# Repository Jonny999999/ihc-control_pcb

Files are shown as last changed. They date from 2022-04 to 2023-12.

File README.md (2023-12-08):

Repo for designing a custom pcb that controlls the electrical components of an IHC-Tractor.

# TOC
- [Links](#links)
- [Overview](#overview)
- [Open Schematic and Layout](#open-schematic-and-layout)
- [Connector Pin-assignment](#connector-pin-assignment)
  * [New Connectors](#new-connectors)
  * [Old Connectors](#old-connectors)
- [I/O List](#i-o-list)
  * [Switches](#switches)
  * [Relays](#relays)
- [Instructions (milling process)](#instructions--milling-process-)
  * [Step 1: export files](#step-1--export-files)
  * [Step 2: generate gcode (holes, traces, outline)](#step-2--generate-gcode--holes--traces--outline-)
  * [Step 3: generate gcode (engraving text)](#step-3--generate-gcode--engraving-text-)
  * [Step 4: mill outline](#step-4--mill-outline)
  * [Step 5: post processing](#step-5--post-processing)
- [Notes for next version (pcb design)](#notes-for-next-version--pcb-design-)
- [Notes for next pcb (milling)](#notes-for-next-pcb-milling)
  * [CNC-Control (WinPC-NC)](#cnc-control--winpc-nc-)
    + [Parameters](#parameters)
    + [Occurred problems](#occurred-problems)
  * [G-code generation (pcb2gcode)](#g-code-generation--pcb2gcode-)
    + [Notes for next time](#notes-for-next-time-)
    + [Gerber export (kicad)](#gerber-export--kicad-)

# Links
- Project documentation: https://pfusch.zone/control-pcb
- Firmware repo: https://github.com/Jonny999999/ihc-control_fw

# Overview
### Schematic
[pcb-ihc_schem_v4-milled-v1.1.pdf](/kicad/export/pcb-ihc_schem_v4-milled-v1.1.pdf)

### PCB-layout
<p align="center">
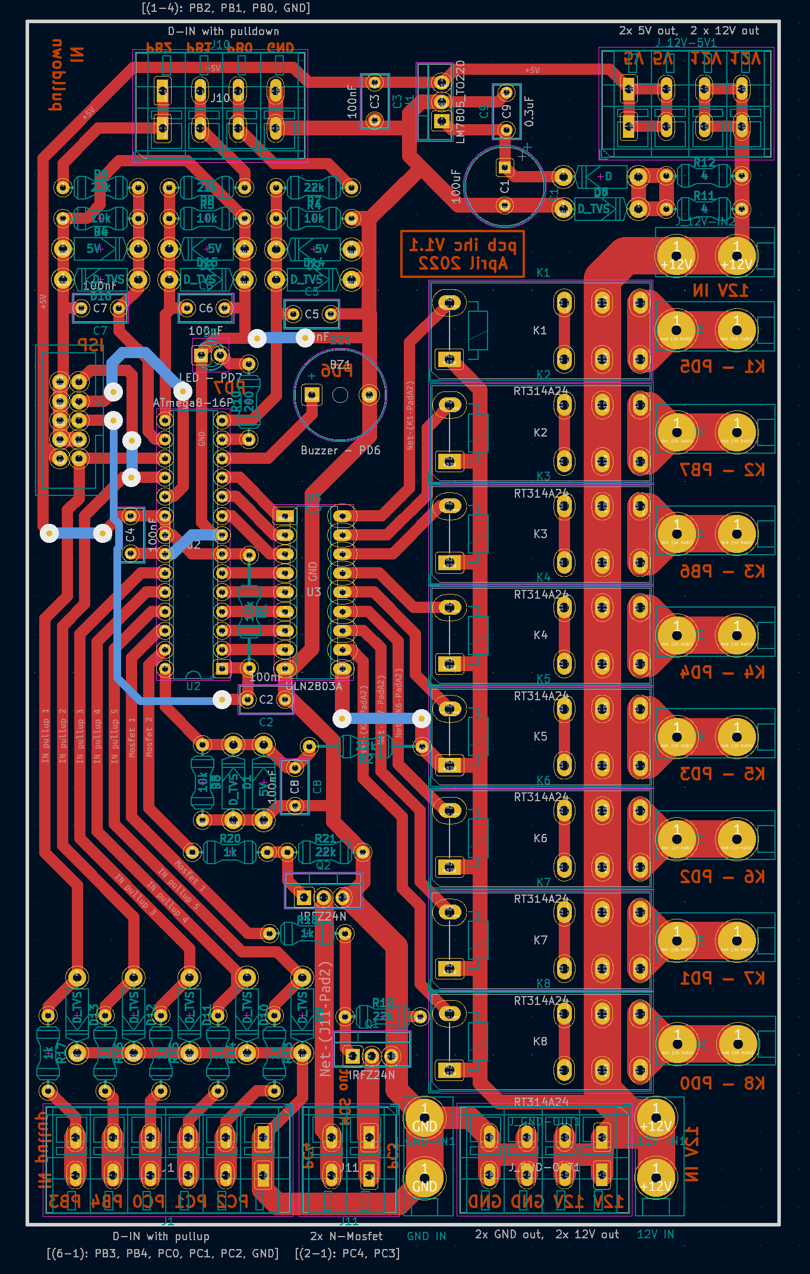
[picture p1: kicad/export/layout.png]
  
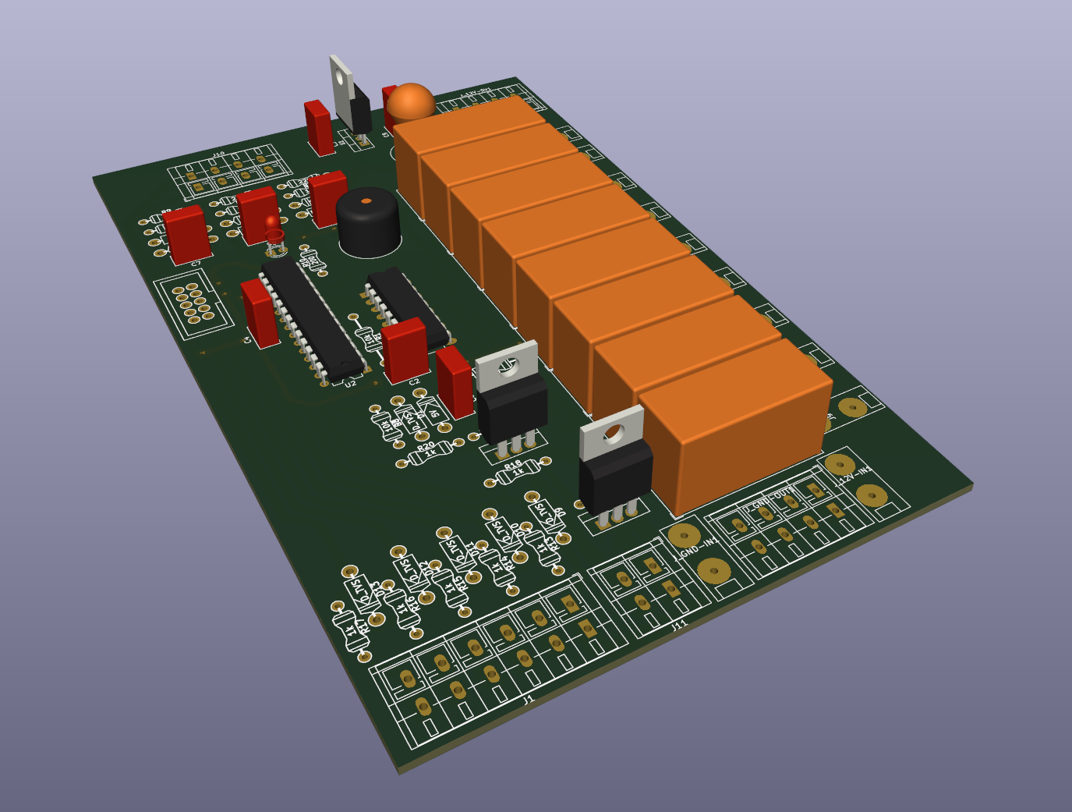
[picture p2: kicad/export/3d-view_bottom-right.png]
  
</p>

# Open Schematic and Layout
Install kicad and open /kicad/pcb-ihc_kicad.kicad_pro  

For quickly viewing the current schematic and layout without installing kicad see exported files in
`kicad/export` or complete documentation at https://pfusch.zone

# Connector Pin-assignment
## New Connectors
See plan in firmware repo: 
https://github.com/Jonny999999/ihc-control_fw/blob/master/connection-plan.pdf

## Old Connectors
### 2 Pole connector 6mm2:
- 1: Starter motor (9)
- 2: Glowplug

### 6 Pole PC (3)
- 1: empty
- 2: Front light right, left (top right)
- 2a: Switch brakelight LS 1/2
- 3: Horn 1/2
- 3a Switch brakelight LS 2/2
- 4: Light left AL, right AR (bottom right)

### 6 Pole PB (2)
- 1: (20) Starter motor (relay) (top left)
- 2: (22) Fuel sensord
- 3: (24) Horn 2/2
- 4: (26) Oil pressure (switch to gnd)
- 5: (28) Temperature sensor
- 6: (30) Voltage regulator alternator (?)

### 6 Pole PA (1)
- 1: (31,32) FD sidelight -> trailer connector
- 2: (37) LB LB Light left -> trailer connector
- 3: (90) Side light BR
- 4: (88) Side light BL
- 5: (43, 42) FA -> trailer connector
- 6: (48) LA light left -> trailer connector

# I/O List
List of required I/O pins for planning the board
## Switches
### Switch to GND (pullup input)
- S_Warning Lights
- S_TurnLeft  toggle
- S_TurnRight toggle
- S_HighBeam  momentary
- S_Warning Lights  toggle
- S_Horn

### Switch to 12V (pulldown input)
- S_ParkingLight
- S_LowBeam
- S_Brake

### Notes
- S_worklight !!! no input left?!

## Relays
- K_BlinkLeft
- K_BlinkRight
- K_ParkingLight
- K_LowBeam
- K_HighBeam
- K_Horn

# Instructions (milling process)
Machine used: Stepcraft 420
## Step 1: export files
- Kicad: Export/plot pcb to gerber files
  Note: Also export User1 layer (includes text for engraving)
- Kicad: Generate drill file
```
back=./in/pcb-ihc_kicad-B_Cu.gbr
front=./in/pcb-ihc_kicad-F_Cu.gbr
outline=./in/pcb-ihc_kicad-Edge_Cuts.gbr
drill=./in/pcb-ihc_kicad-PTH.drl
see config file: pcb2gcode/millproject
```

## Step 2: generate gcode (holes, traces, outline)
- run pcb2gcode: `ihc-control_pcb/pcb2gcode> pcb2gcode`  
  will use millproject file for parameters as default config

## Step 3: generate gcode (engraving text)
- Kicad: moved text to be engraved into pcb on separate layer (User1)
- Also export/plot User1 layer with other gerber files
- Use separate millproject_text parameter file with pcb2gcode
  `pcb2gcode --config millproject_text`
NOTE: also include outline and maybe front in that millproject, even though that output is not used. It is necessary that the origin fits, otherwise there will be an offset!
- The trick was to use a negative offest (almost half the line width) to get more or less clean characters
- Generates pcb2gcode/out/text/back.ngc
Note: check if there is an offset/scaling issue to other files (back, drill). last time text got engraved into traces even though it matched on the other side

## Step 4: mill outline
Was not necessary in this case because size already matched

## Step 5: post processing
- Slightly smooth copper layer of pcb using grinding wool
- Drill holes for big 4mm2 2-pin terminals to 1.5mm if drilled with just 1mm on cnc

# Notes for next version (pcb design)
- Add resistor and diode for slowly charging the input capacitor (limit charging current)
- Add diode and/or jumper for isp programmer. Noticed that current is flowing from board 5v to programmer (input resistor got hot - only when programme connected) (alternatively jumper on programmer can be used for this...)
- ADD FUSES
  - Add fuse for 12v supply to 5v regulator
  - Fuses for mosfets?
  - Fuses for relay?
- Add mounting holes / at least make some space for third hole
- Slightly smaller size for easier cnc-milling

# Notes for next pcb milling
## CNC-Control (WinPC-NC)
### Parameters
- WinPC-NC has weird default z coorinates direction
  => **Z coordinates have to be inverted (!!!!!)** (otherwise will crash)
  -> parameters -> dateiformat -> z-koordinaten invertieren
- Change units to mm/min instead of default mm/s
### Occurred problems
- Problem Stepper not moving, only producing noise, but winpc-nc actually thinks that it moved coordinates - especially happened for Z-Axis
  - Solution 1: remove top section of gcode (simple G1 commands worked - see gcode generated with estlcam that is compatible)
  - Solution 2: switch from windows in Virtualbox to native windows

## G-code generation (pcb2gcode)
### notes for next time:
TODO: merge this section with milling instructions?
- Text engraving: slightly reduce Z depth 
- Zero Z-axis on multiple places: 
  At 2 edges pcb material was apparently lower, thus only scratched the surface -> had to mill again
- Zero-XY NOT at file origin! (the offset is caused by outline cutter diameter) 
  - 1. Load outline gcode, zero x,y next to border (note offset) 
  - 2. Confirm with moving on other side of pcb
- Make screenshot of absolute coordinates of origin (in case of accidential shift / position loss)
- Check position before drilling holes
- Fixing the pcb: Screws around the pcb are probably enough (check bend)
- When generating gcode for text separately, also include at least outline, otherwise there is an offset (origin makes no sense)

### Gerber export (kicad)
- design pcb slightly smaller for more tolerance...
- define custom origin 
  => tried this, setting "drill/place file origin" and tick the checkbox at plot, but had no effect to pcb2gcode in any way
- check if origin is the same in every gerber/gcode file (verify with gcode viewer?)

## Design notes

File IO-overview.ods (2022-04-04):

 | IN Switches |  |  |  |  | OUT Relay
N. | Location | Variable name | Switch type | Connection type | N. | Variable name
1 | dashboard | S_Warning Lights | toggle | NO, low | 1 | K_BlinkLeft
2 | dashboard | S_TurnLeft | toggle | NO, low | 2 | K_BlinkRight
3 | dashboard | S_TurnRight | toggle | NO, low | 3 | K_ParkingLight
4 | dashboard | S_HighBeam | momentary | NO, low | 4 | K_LowBeam
5 | dashboard | S_Horn | momentary | NO, low | 5 | K_HighBeam
 |  |  |  |  | 6 | K_Horn?
6 | Key | S_ParkingLight | toggle | NO, high | 7 | K_hinten
7 | Key | S_LowBeam | toggle | NO, high | 8
 |  |  |  |  |  | bremslicht blinkern nur hinten
8 | Brake | S_Brake | momentary | NO, high
 |  |  |  |  |  | OUT Direct
 | IN Analog |  |  |  | 1 | LED switch???
 | Location | Variable name |  |  | 2 | LED PCB
1 | pcb | IN_Voltage |  |  | 3 | Buzzer
 | Notes / Ideas: |  |  |  |  | OUT Mosfet
 | LED for each relay?
 | switch horn?

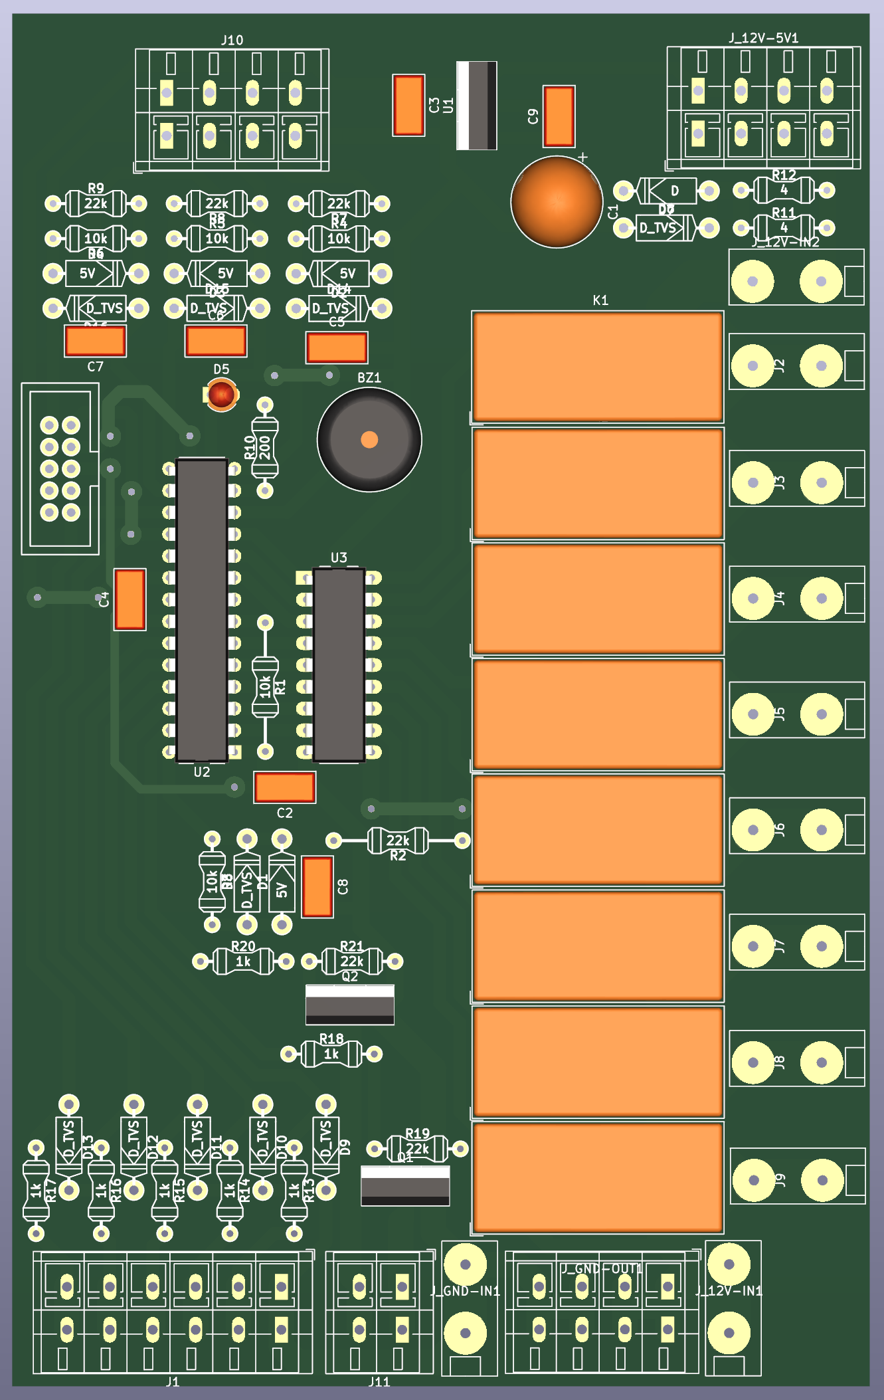
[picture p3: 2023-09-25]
kicad/export/3d-view_top.png

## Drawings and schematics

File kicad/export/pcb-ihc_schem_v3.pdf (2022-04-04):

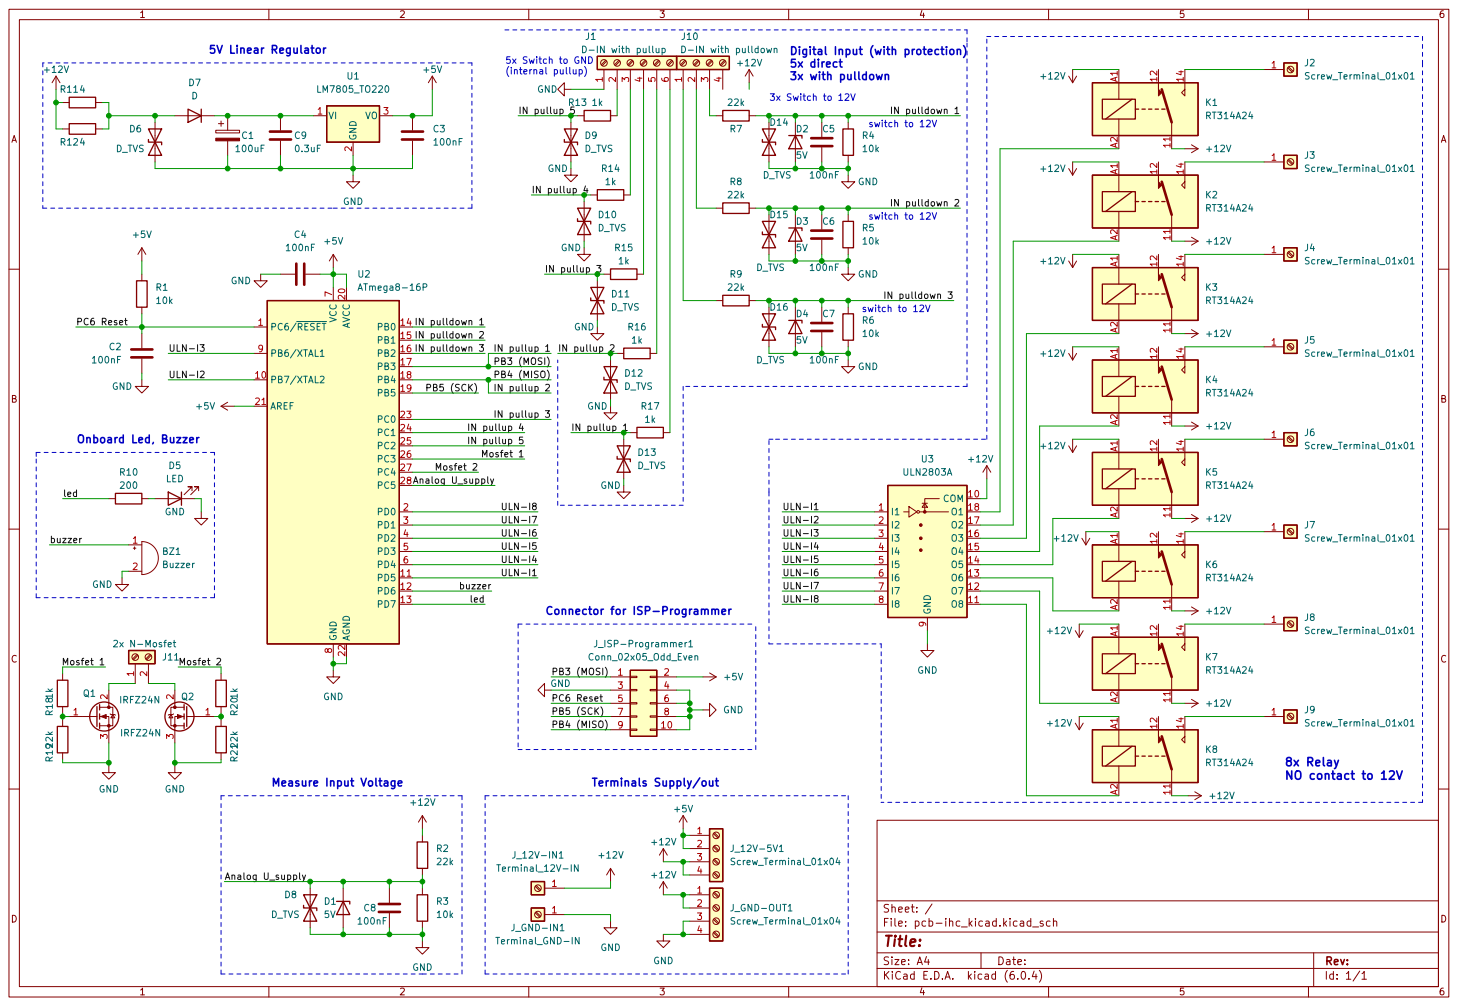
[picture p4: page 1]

switch to 12V Measure Input Voltage

IN pullup 3
IN pullup 3 ULN-I7 PB4 (MISO) ULN-I5 ULN-I6

switch to 12V Onboard Led, Buzzer

Connector for ISP-Programmer

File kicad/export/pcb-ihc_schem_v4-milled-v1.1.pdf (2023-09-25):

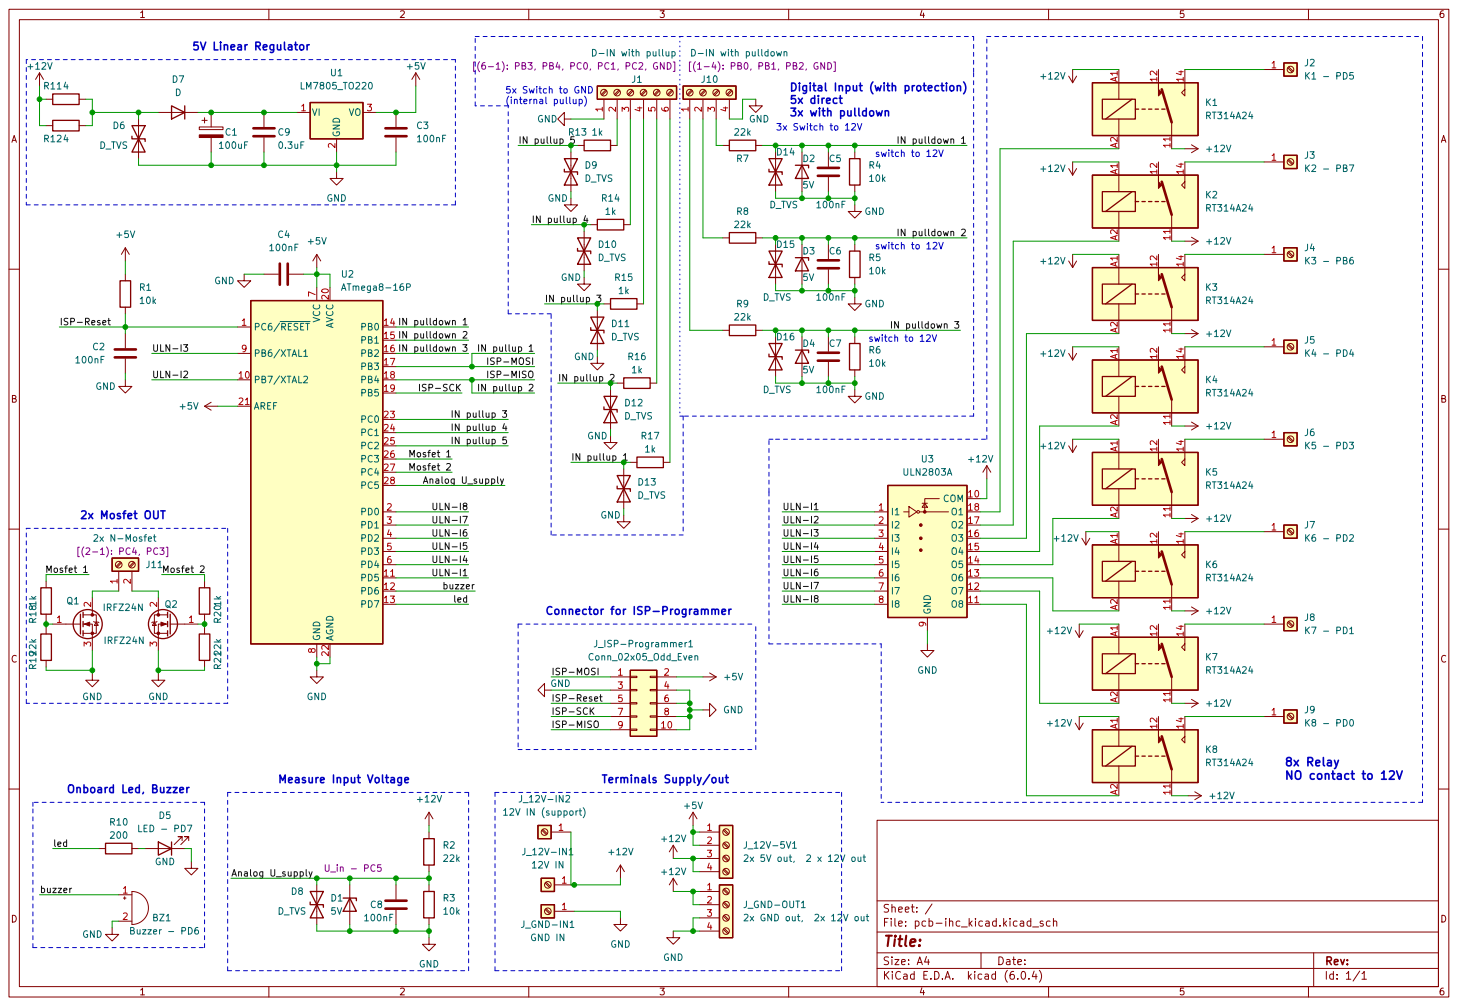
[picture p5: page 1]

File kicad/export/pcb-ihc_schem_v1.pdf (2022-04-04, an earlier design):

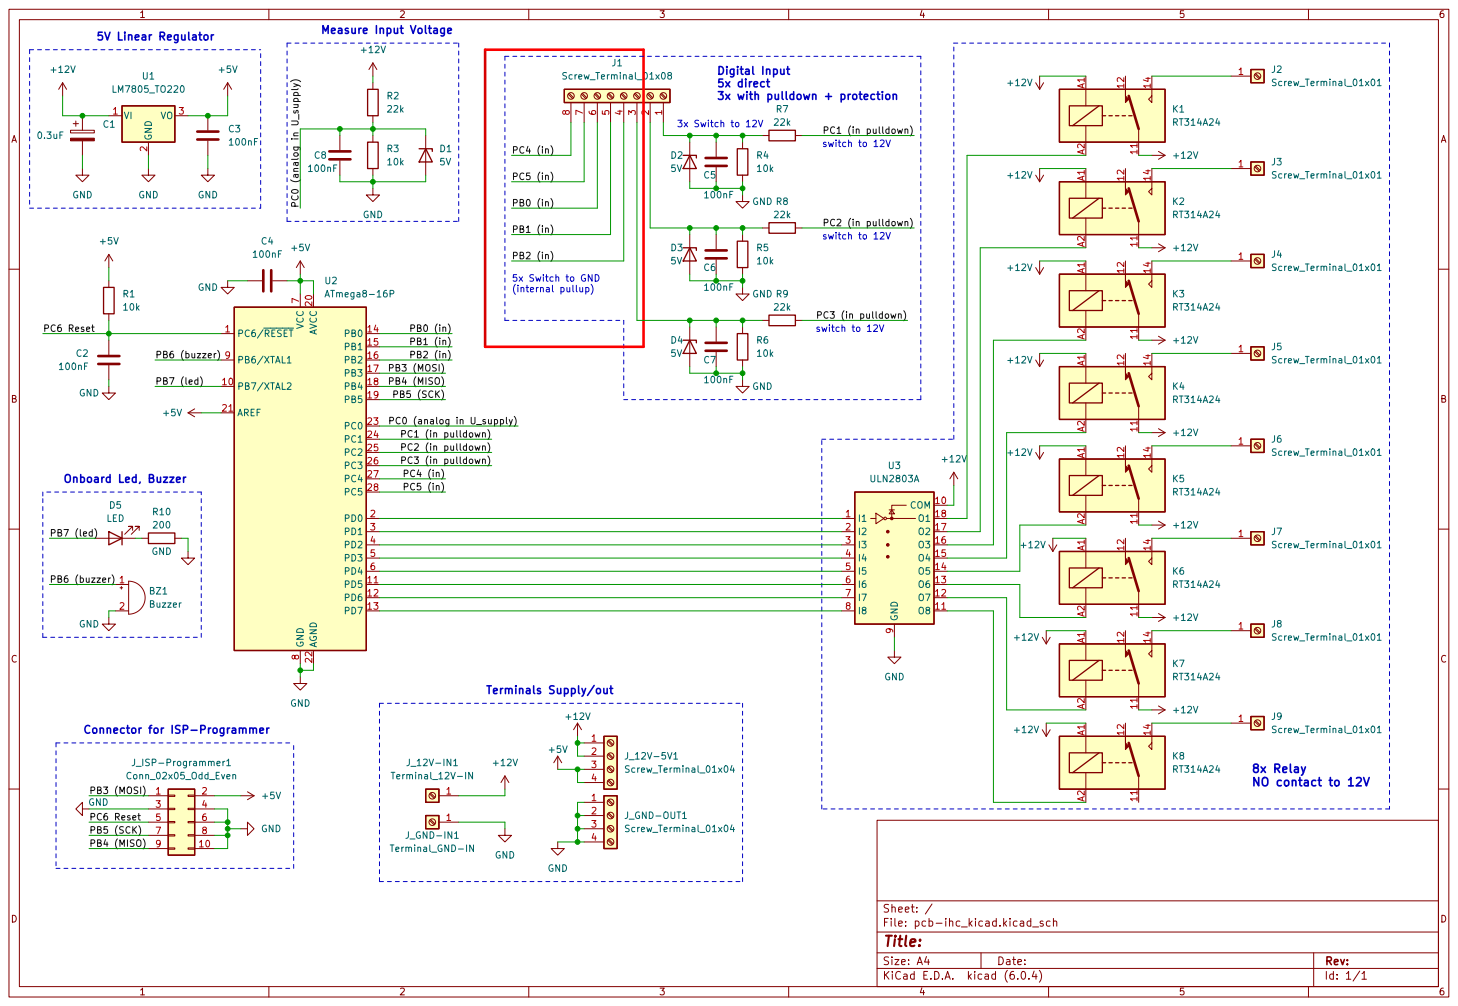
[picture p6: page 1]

Digital Input 5x direct 3x with pulldown + protection

I3 3
I4 4
I5 5
I6 6
I7 7

File: pcb-ihc_kicad.kicad_sch Sheet: / GND

Connector for ISP-Programmer

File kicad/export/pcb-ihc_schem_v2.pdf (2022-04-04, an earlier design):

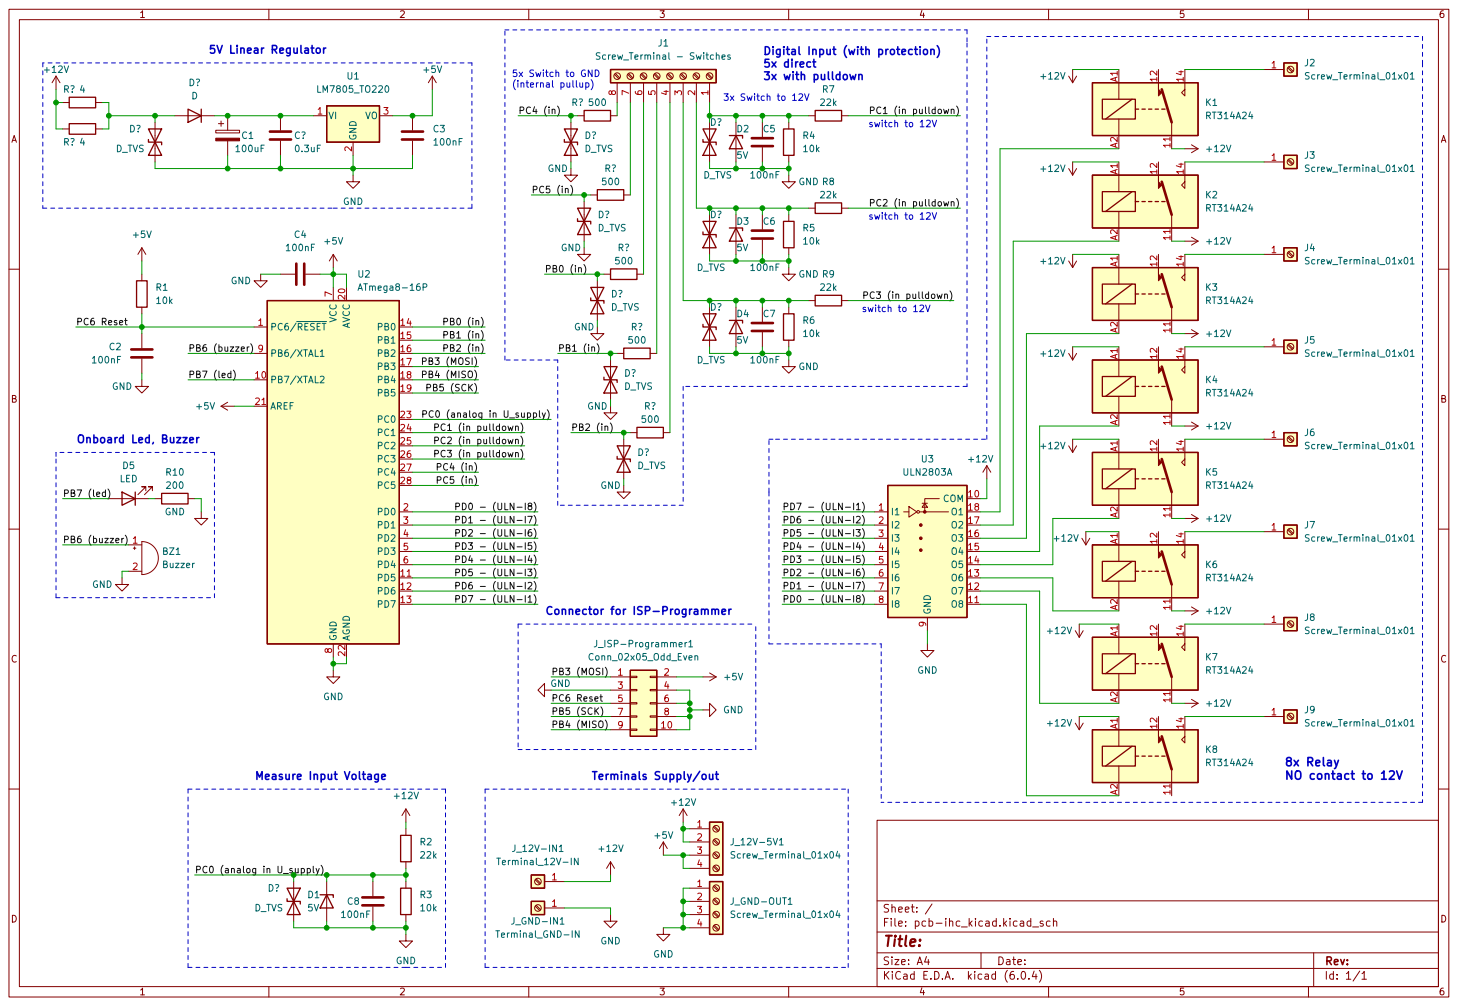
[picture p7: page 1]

Digital Input (with protection) 5x direct 3x with pulldown

Connector for ISP-Programmer

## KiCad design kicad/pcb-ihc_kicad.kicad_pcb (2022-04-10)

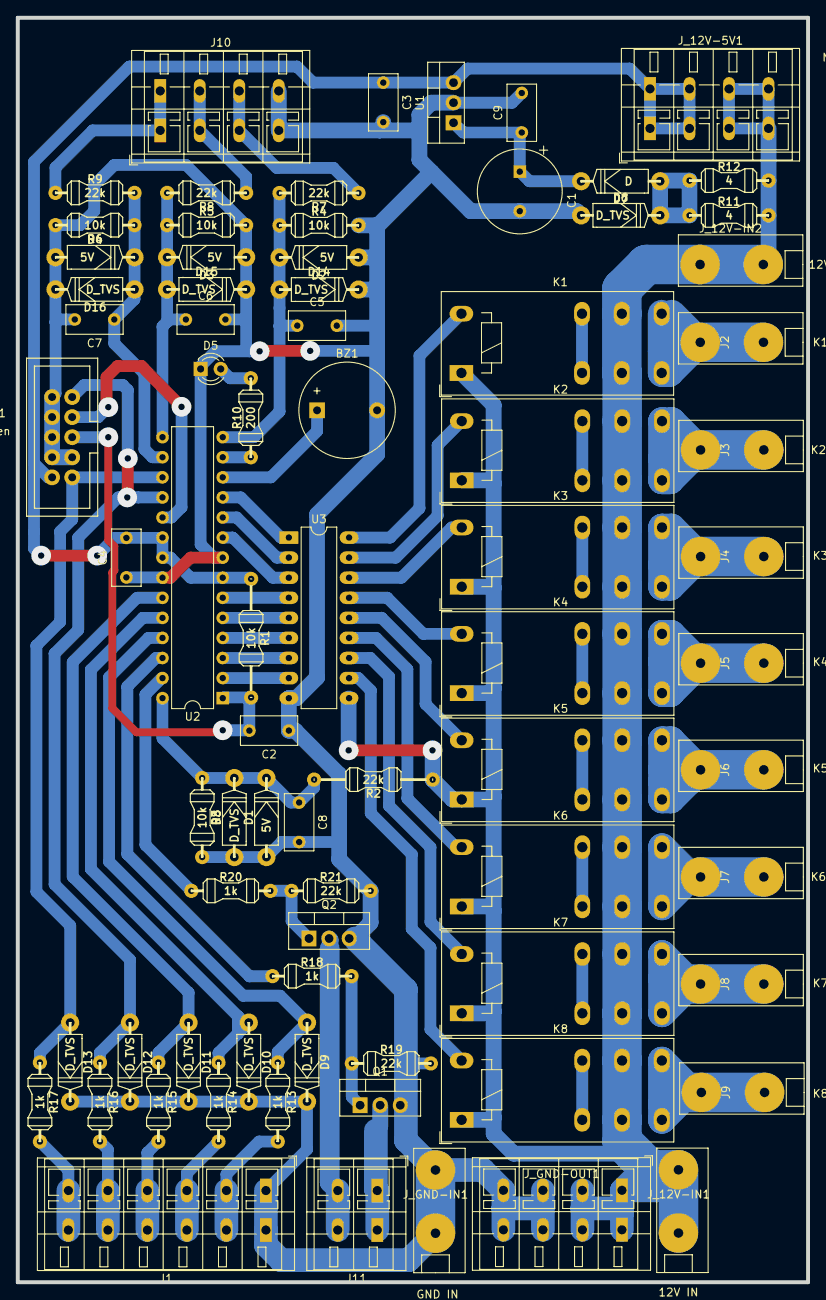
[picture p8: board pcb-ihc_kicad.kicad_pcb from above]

Board: 2 copper layers, 100.0 x 160.0 mm, 77 parts (0 on the bottom side), 57 nets.

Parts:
BZ1: Buzzer - PD6; Buzzer_12x9.5RM7.6
C1: 100uF; CP_Radial_Tantal_D10.5mm_P5.00mm
C2, C3, C4, C5, C6, C7, C8: 100nF; C_Rect_L7.0mm_W3.5mm_P5.00mm
C9: 0.3uF; C_Rect_L7.0mm_W3.5mm_P5.00mm
D1, D2, D3, D4: 5V; my_D10_11
D5: LED - PD7; LED_D3.0mm
D6, D8, D9, D10, D11, D12, D13, D14, D15, D16: D_TVS; my_D10_11
D7: D; my_D10_11
J1: D-IN with pullup; TerminalBlock_WAGO_236-406_1x06_P5.00mm_45Degree
J2: K1 - PD5; my_KlemmeWago2604-single
J3: K2 - PB7; my_KlemmeWago2604-single
J4: K3 - PB6; my_KlemmeWago2604-single
J5: K4 - PD4; my_KlemmeWago2604-single
J6: K5 - PD3; my_KlemmeWago2604-single
J7: K6 - PD2; my_KlemmeWago2604-single
J8: K7 - PD1; my_KlemmeWago2604-single
J9: K8 - PD0; my_KlemmeWago2604-single
J10: D-IN with pulldown; TerminalBlock_WAGO_236-404_1x04_P5.00mm_45Degree
J11: 2x N-Mosfet; TerminalBlock_WAGO_236-402_1x02_P5.00mm_45Degree
J_12V-5V1: 2x 5V out, 2 x 12V out; TerminalBlock_WAGO_236-404_1x04_P5.00mm_45Degree
J_12V-IN1: 12V IN; my_KlemmeWago2604-single
J_12V-IN2: 12V IN (support); my_KlemmeWago2604-single
J_GND-IN1: GND IN; my_KlemmeWago2604-single
J_GND-OUT1: 2x GND out, 2x 12V out; TerminalBlock_WAGO_236-404_1x04_P5.00mm_45Degree
J_ISP-Programmer1: Conn_02x05_Odd_Even; my_wannenstecker_2x5
K1, K2, K3, K4, K5, K6, K7, K8: RT314A24; Relay_SPDT_Schrack-RT1-16A-FormC_RM5mm
Q1, Q2: IRFZ24N; TO-220-3_Vertical
R1: 10k; my_R15-long
R2: 22k; my_R15-long
R3, R4, R5, R6: 10k; my_R10
R7, R8, R9, R19, R21: 22k; my_R10
R10: 200; my_R10
R11, R12: 4; my_R10
R13, R14, R15, R16, R17, R18, R20: 1k; my_R10
U1: LM7805_TO220; TO-220-3_Vertical
U2: ATmega8-16P; DIP-28_W7.62mm
U3: ULN2803A; DIP-18_W7.62mm_LongPads

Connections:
+5V: C3.1, C4.2, J_12V-5V1.1, J_12V-5V1.2, J_ISP-Programmer1.2, R1.1, U1.3 (VO), U2.7 (VCC), U2.20 (AVCC), U2.21 (AREF)
+12V: J_12V-5V1.3, J_12V-5V1.4, J_12V-IN1.1, J_12V-IN2.1, J_GND-OUT1.1, J_GND-OUT1.2, K1.11, K1.A1, K2.11, K2.A1, K3.11, K3.A1, K4.11, K4.A1, K5.11, K5.A1, K6.11, K6.A1, K7.11, K7.A1, K8.11, K8.A1, R2.1, R11.2, R12.2, U3.10 (COM)
/Analog U_supply: C8.1, D1.1 (K), D8.1 (A1), R2.2, R3.1, U2.28 (PC5)
/IN pulldown 1: C5.1, D2.1 (K), D14.2 (A2), R4.1, R7.2, U2.14 (PB0)
/IN pulldown 2: C6.1, D3.1 (K), D15.2 (A2), R5.1, R8.2, U2.15 (PB1)
/IN pulldown 3: C7.1, D4.1 (K), D16.2 (A2), R6.1, R9.2, U2.16 (PB2)
/IN pullup 1: D13.2 (A2), J_ISP-Programmer1.1, R17.1, U2.17 (PB3)
/IN pullup 2: D12.2 (A2), J_ISP-Programmer1.9, R16.1, U2.18 (PB4)
/IN pullup 3: D11.2 (A2), R15.1, U2.23 (PC0)
/IN pullup 4: D10.2 (A2), R14.1, U2.24 (PC1)
/IN pullup 5: D9.2 (A2), R13.1, U2.25 (PC2)
/ISP-Reset: C2.2, J_ISP-Programmer1.5, R1.2, U2.1 (PC6/~RESET)
/ISP-SCK: J_ISP-Programmer1.7, U2.19 (PB5)
/Mosfet 1: R18.1, U2.26 (PC3)
/Mosfet 2: R20.1, U2.27 (PC4)
/ULN-I1: U2.11 (PD5), U3.1 (I1)
/ULN-I2: U2.10 (PB7/XTAL2), U3.2 (I2)
/ULN-I3: U2.9 (PB6/XTAL1), U3.3 (I3)
/ULN-I4: U2.6 (PD4), U3.4 (I4)
/ULN-I5: U2.5 (PD3), U3.5 (I5)
/ULN-I6: U2.4 (PD2), U3.6 (I6)
/ULN-I7: U2.3 (PD1), U3.7 (I7)
/ULN-I8: U2.2 (PD0), U3.8 (I8)
/buzzer: BZ1.1 (-), U2.12 (PD6)
/led: R10.1, U2.13 (PD7)
GND: BZ1.2 (+), C1.2, C2.1, C3.2, C4.1, C5.2, C6.2, C7.2, C8.2, C9.2, D1.2 (A), D2.2 (A), D3.2 (A), D4.2 (A), D5.1 (K), D6.2 (A2), D8.2 (A2), D9.1 (A1), D10.1 (A1), D11.1 (A1), D12.1 (A1), D13.1 (A1), D14.1 (A1), D15.1 (A1), D16.1 (A1), J1.1, J10.4, J_GND-IN1.1, J_GND-OUT1.3, J_GND-OUT1.4, J_ISP-Programmer1.3, J_ISP-Programmer1.4, J_ISP-Programmer1.6, J_ISP-Programmer1.8, J_ISP-Programmer1.10, Q1.3 (S), Q2.3 (S), R3.2, R4.2, R5.2, R6.2, R19.2, R21.2, U1.2 (GND), U2.8 (GND), U2.22 (AGND), U3.9 (GND)
unnamed: C1.1, C9.1, D7.1 (K), U1.1 (VI)
unnamed: D5.2 (A), R10.2
unnamed: D6.1 (A1), D7.2 (A), R11.1, R12.1
unnamed: J1.2, R13.2
unnamed: J1.3, R14.2
unnamed: J1.4, R15.2
unnamed: J1.5, R16.2
unnamed: J1.6, R17.2
unnamed: J2.1, K1.14
unnamed: J3.1, K2.14
unnamed: J4.1, K3.14
unnamed: J5.1, K4.14
unnamed: J6.1, K5.14
unnamed: J7.1, K6.14
unnamed: J8.1, K7.14
unnamed: J9.1, K8.14
unnamed: J10.1, R9.1
unnamed: J10.2, R8.1
unnamed: J10.3, R7.1
unnamed: J11.1, Q1.2 (D)
unnamed: J11.2, Q2.2 (D)
unnamed: K1.A2, U3.18 (O1)
unnamed: K2.A2, U3.17 (O2)
unnamed: K3.A2, U3.16 (O3)
unnamed: K4.A2, U3.15 (O4)
unnamed: K5.A2, U3.14 (O5)
unnamed: K6.A2, U3.13 (O6)
unnamed: K7.A2, U3.12 (O7)
unnamed: K8.A2, U3.11 (O8)
unnamed: Q1.1 (G), R18.2, R19.1
unnamed: Q2.1 (G), R20.2, R21.1

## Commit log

2022-04-04 init
    pcb layout is in progress, schematic needs optimizations
    [IO-overview.ods, pcb-ihc_kicad.dsn, pcb-ihc_kicad.kicad_pcb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]
2022-04-04 Add 2x Mosfet, Change labels, Change layout
    [pcb-ihc_kicad.kicad_pcb, pcb-ihc_kicad.kicad_sch, pcb-ihc_kicad_7.dsn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]
2022-04-04 Optimize layout
    [pcb-ihc_kicad.kicad_pcb, pcb-ihc_kicad_8.dsn, pcb-ihc_kicad_9.dsn]
2022-04-04 Routing first version ready for validation
    in this commit the entire routing of tracks was done. next step
    validation and optimizations.
    [pcb-ihc_kicad.kicad_pcb, pcb-ihc_kicad.kicad_sch, pcb-ihc_kicad_routing_1.dsn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]
2022-04-05 Optimize routing and layout
    - fix track width on several locations (1.5 to 2mm)
    - minor changes in routing
    - move relays closer together
    - add additional 12V input terminal
    [pcb-ihc_kicad.kicad_pcb, pcb-ihc_kicad.kicad_sch]
2022-04-05 Add gitignore, remove backups
    Add gitignore to ignore auto-save and backup files from kicad
2022-04-05 Add terminal descriptions, Clean up schematic
    - Add detailed terminal/connector descriptions (e.g. which uC pin)
    - Positioned labels in layout outside of pcb
    - cleanup in schematic reorder groups, fix boxes...
    [pcb-ihc_kicad.kicad_pcb, pcb-ihc_kicad.kicad_sch]
2022-04-06 Swap Layers Front/Back Tracks
    Noticed in 3d viewer that tracks were on the same side as components...
    swaped F.Cu and B.Cu using " Edit -> Swap layers ". Now tracks are on
    the other side...
    [pcb-ihc_kicad.kicad_pcb]
2022-04-07 Add text to copper back layer
    Add description of terminals (desc, controller pin) as text to copper
    layer. The plan is that the text is actually milled onto the pcb
    (like tracks)
    [pcb-ihc_kicad.kicad_pcb]
2022-04-07 Add pcb2gcode
    Created folder for pcb2gcode (to convert gerber files from kicad to
    gcode for winpc)
    Add config file
    tried to extract parameters from old gcode files of electric kart
    project (also converted with pcb2gcode)
    worked with pcb2gcode gui for some time but noticed it is quite
    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
    [pcb-ihc_kicad-B_Cu.gbr, pcb-ihc_kicad-Edge_Cuts.gbr, pcb-ihc_kicad-F_Cu.gbr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]
2022-04-07 Renamed kicad folder
    renamed folder pcb-ihc_kicad to kicad (project folder name describes
    project anyways)
    [pcb-ihc_kicad.kicad_pcb, pcb-ihc_kicad.kicad_sch]
2022-04-08 Add Readme, Add ihc-schematic
    Add readme for notes about the project
    Add downloaded ihc schematic for identification of pins
2022-04-08 Add gcode file for milling 162x102 plane for pcb
    copied old file generated using estlcam that mills an area 162x102mm
    0.7mm deep using a 6mm cutter
2022-04-09 Remove and ignore svg files of pcb2gcode from git
2022-04-09 Move text to User1 layer, adjust positions
    Move text that should be engraved to pcb from copper-back layer to user1
    layer (=> can be handled / processed separately with other parameters by
    pcb2gcode)
    also make line width to 0.3 for previous smaller text
    [pcb-ihc_kicad.kicad_pcb]
2022-04-09 pcb2gcode: Add millproject_text config
    Add separate parameter file for engraving text using separate exported User1
    layer
    [pcb-ihc_kicad-B_Cu.gbr, pcb-ihc_kicad-Edge_Cuts.gbr, pcb-ihc_kicad-F_Cu.gbr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]
2022-04-09 pcb2gcode: Change several parameters: zsafe, feed, drill...
    change zsafe from 5 to 2mm (z takes too long to move - faster)
    change zchange from 40 to 30 (unnecessary high exceeded working range
    when test-milling in air)
    change millfeed from 300 to 500 (appeared to slow - more room for adjustments to greater speeds while milling 0-200%)
    add drills avaialbe=0.8,1 (drilling with those diameters ony anyways -
    no unnecessary tool changes that get skipped anyways)
2022-04-09 readme: pcb2gcode details, IHC-schematic interpretation
    Tried to identify connector pins using ihc schematic
    Added description of engraving text using kicad and pcb2gcode
2022-04-09 Generated gcode of current pcb version
    [pcb-ihc_kicad-B_Cu.gbr, pcb-ihc_kicad-Edge_Cuts.gbr, pcb-ihc_kicad-F_Cu.gbr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]
2022-04-09 First milling: Update readme, gcode files
    First pcb got produced, there were several issues - see readme "notes
    for next time milling"
    gcode for text engraving is apparently scaled wrong? does not line up at
    the other side of pcb - this has to be looked into
    [pcb-ihc_kicad-User_2.gbr]
2022-04-10 Reduce length of pcb
    Layout: move top components closer together to have more "free space" on
    the top thus more tolerance when milling
    [pcb-ihc_kicad.kicad_pcb]
2022-04-10 pcb2gcode: Change outline side and cutter-diameter
    cutter diameter caused offset of origin in gcode files, which was quite
    confusing at first try. changed from 3mm to 0mm in both millproject and
    millproject_text
    changed cute-side to back, default was front which mirrored the gcode
    (wrong origin position)
2022-04-10 Minor optimization of text position
    [pcb-ihc_kicad.kicad_pcb]
2022-04-10 Generate gcode for second milling procedure
    Exported gerber files from current pcb layout
    generated gcode with applied optimizations learned from last milling
    [pcb-ihc_kicad-B_Cu.gbr, pcb-ihc_kicad-Edge_Cuts.gbr, pcb-ihc_kicad-F_Cu.gbr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]
2022-04-10 Fix incorrect label/text 'PB2' <> 'PB0'
    The description of input terminal "in pulldown" was inverted
    Fix order on User1 layer and F.Fab in pcbnew
    [pcb-ihc_kicad.kicad_pcb]
2022-05-07 Update readme: Add nots for next version (layout)
    Fix formatting for schematic headlines
    Add further notes about pcb layout design optimizations (fuses, mounting holes)
2023-09-25 Update README, Add export folder, schematic
    Add export folder with schematic and layout screenshots
    Update Readme: translate to english, add TOC, cleanup
